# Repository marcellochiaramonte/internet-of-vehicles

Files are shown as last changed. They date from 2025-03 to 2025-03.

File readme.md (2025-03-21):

Internet of Vehicles Project to bring IoT into Electric Vehicles

➡️ [Micropython Pycom Module Code](./2_Software_Module)

➡️ [Fullstack Web App Springboot Angular](./3_Software_Cloud/iov-full-stack-app)

list
battery
map
system
board

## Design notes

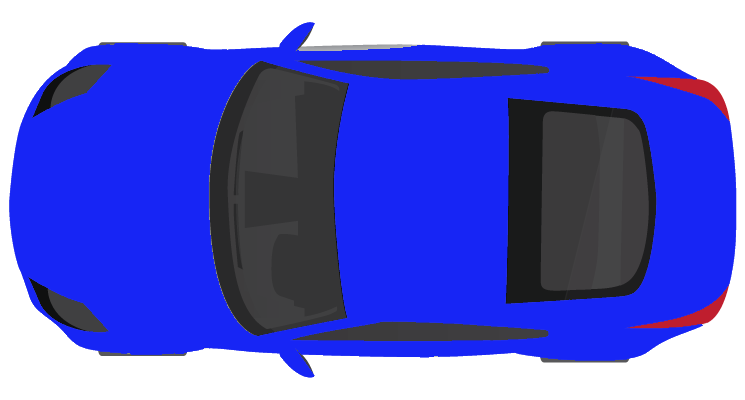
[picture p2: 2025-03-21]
3_Software_Cloud/iov-full-stack-app/frontend-map/iov-frontend/src/assets/img/car-blue.png

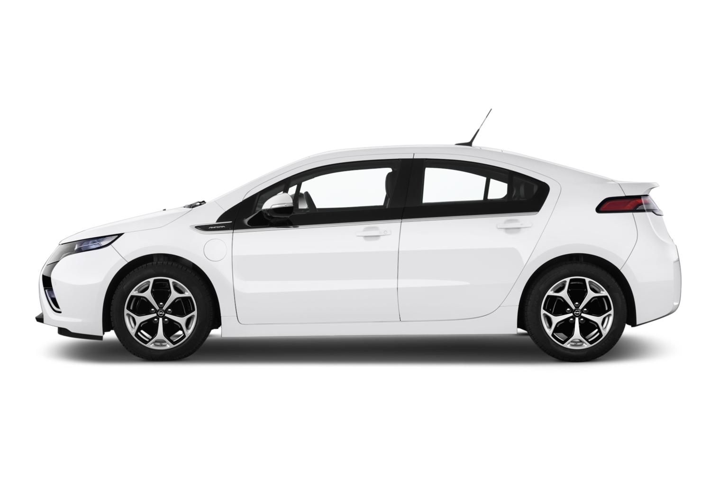
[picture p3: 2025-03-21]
3_Software_Cloud/iov-full-stack-app/frontend-map/iov-frontend/src/assets/img/opel-ampera.png

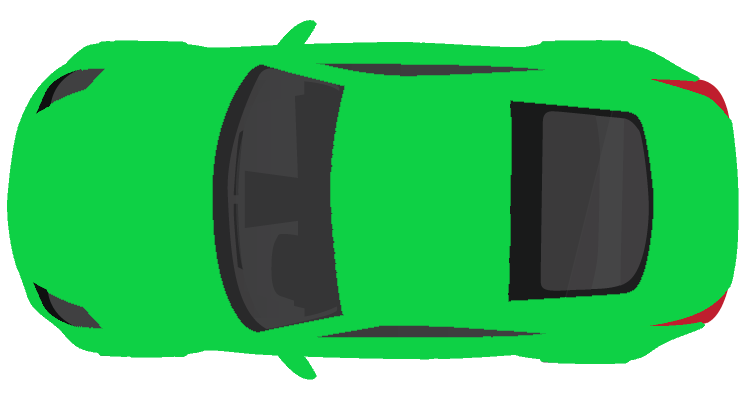
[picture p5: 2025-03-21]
3_Software_Cloud/iov-full-stack-app/frontend-map/iov-frontend/src/assets/img/car-green.png

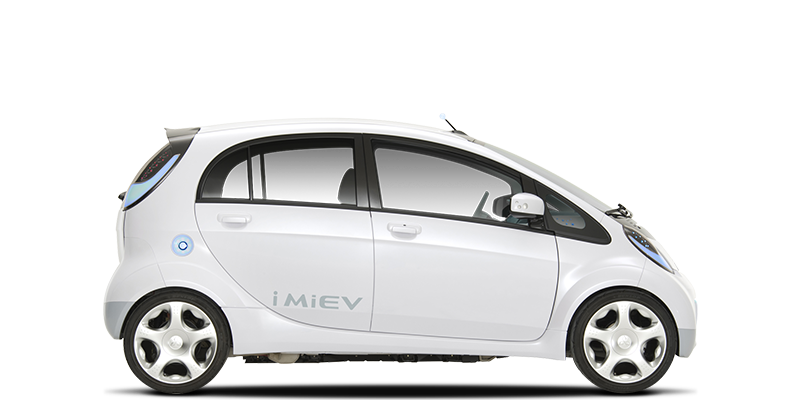
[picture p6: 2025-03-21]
3_Software_Cloud/iov-full-stack-app/frontend-map/iov-frontend/src/assets/img/mitsubishi-i-miev.png

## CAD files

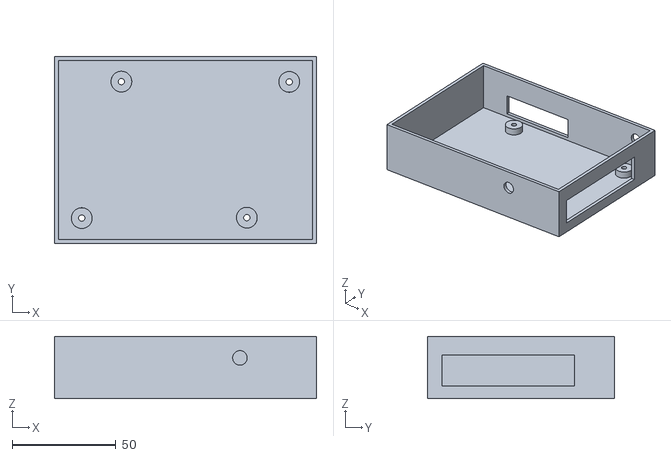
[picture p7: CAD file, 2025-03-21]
4_Case_3D_Printed/stl_models/box/bottom_walls_full_assembly.stl
126.0 x 90.0 x 30.0

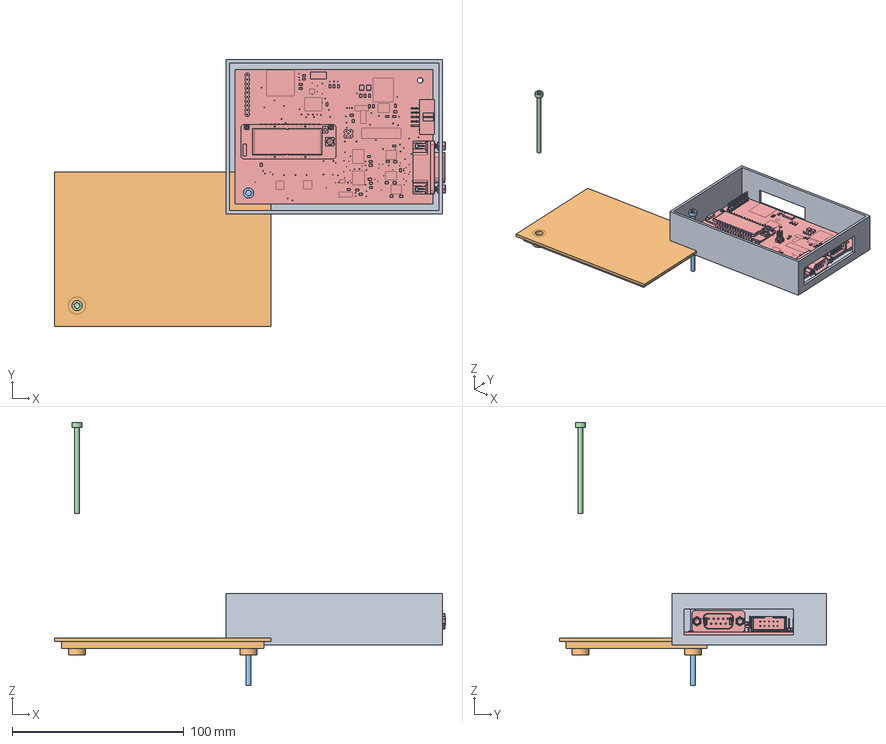
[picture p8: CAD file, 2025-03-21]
4_Case_3D_Printed/freecad_models/AA_full_assembly.FCStd
227.5 x 155.5 x 153.1 mm
bottom_walls_full_assembly_001
cover_mounted_001
m3screw_001
m3screw_002
OVMS v7 v11_001

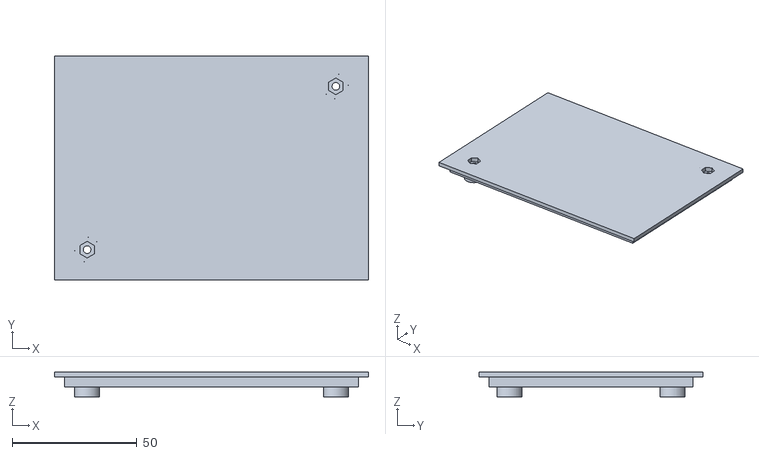
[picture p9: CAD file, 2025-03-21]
4_Case_3D_Printed/stl_models/cover/cover_mounted.stl
126.0 x 90.0 x 10.0

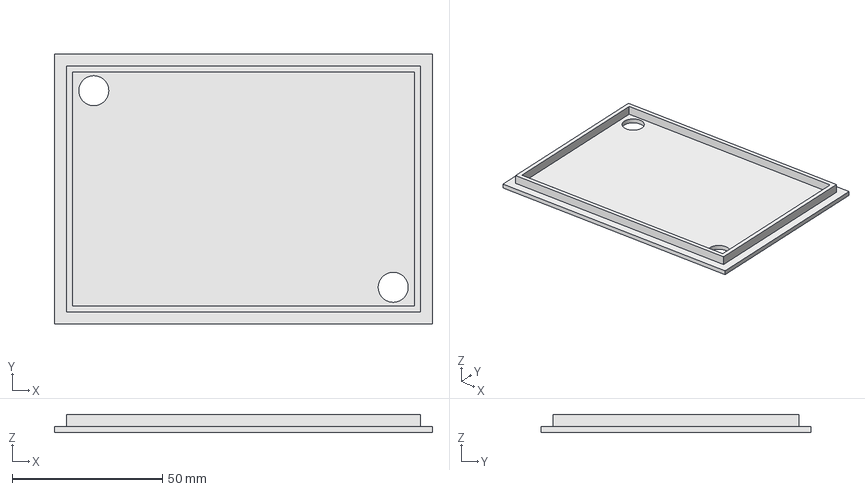
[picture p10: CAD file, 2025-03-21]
4_Case_3D_Printed/freecad_models/cover.FCStd
126.0 x 90.0 x 6.00 mm

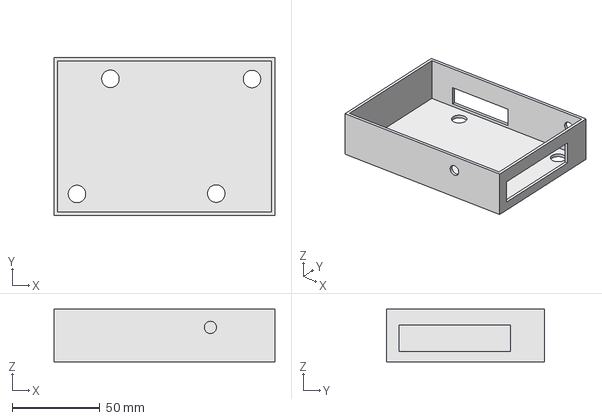
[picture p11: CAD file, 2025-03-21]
4_Case_3D_Printed/freecad_models/bottom_and_walls.FCStd
126.0 x 90.0 x 30.0 mm

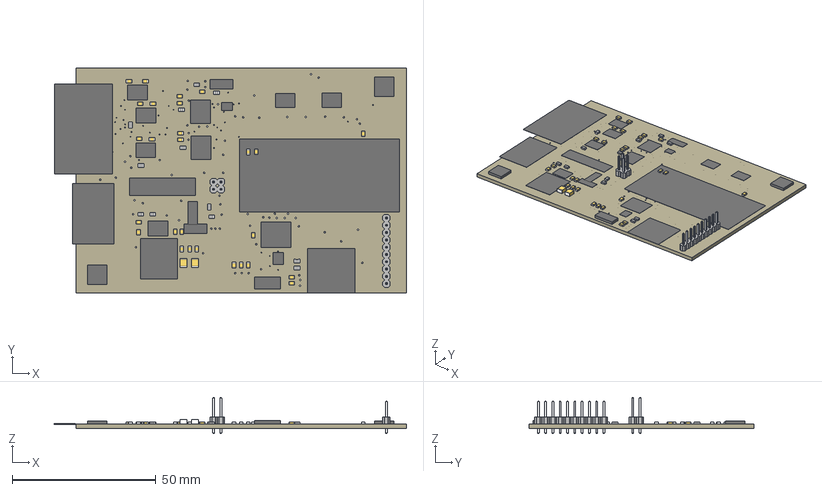
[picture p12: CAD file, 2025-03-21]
4_Case_3D_Printed/freecad_models/iov-board-1.stp
122.6 x 78.3 x 12.6 mm
Board
3_3_UH
SOP65P780X200-28N
DDA0008J
LITTLEFUSE_658
TSSOP20_MC_MCH x 2
OSC_ECS-2520S25-250-FN-TR
D8 x 3
SOT143
USB-B-MICRO-SMD
3,2 x 2
503182-1852_MOL
1X10
2X02
SW_PTS647SM38SMTR2LFS_CNK x 2
PYCOM_GPY-28
C0805 x 27
C1210 x 2
R0805 x 12
SMA_STM x 3
TE_5747840-6

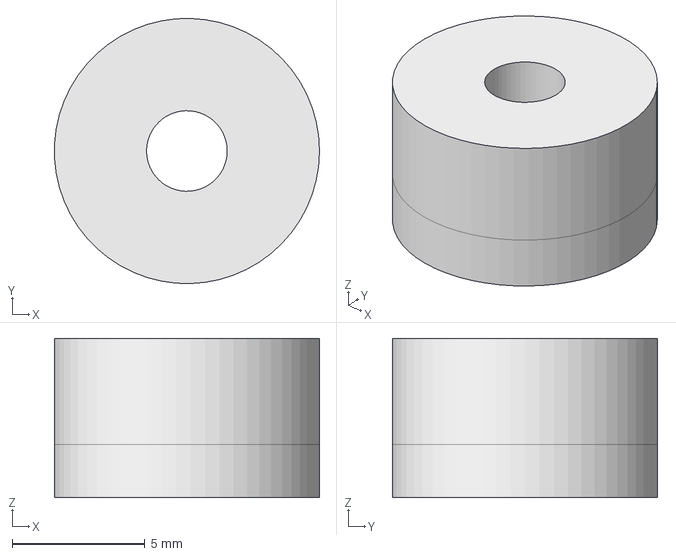
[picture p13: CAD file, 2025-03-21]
4_Case_3D_Printed/freecad_models/screw_holder_bottom.FCStd
9.99 x 10.00 x 6.00 mm

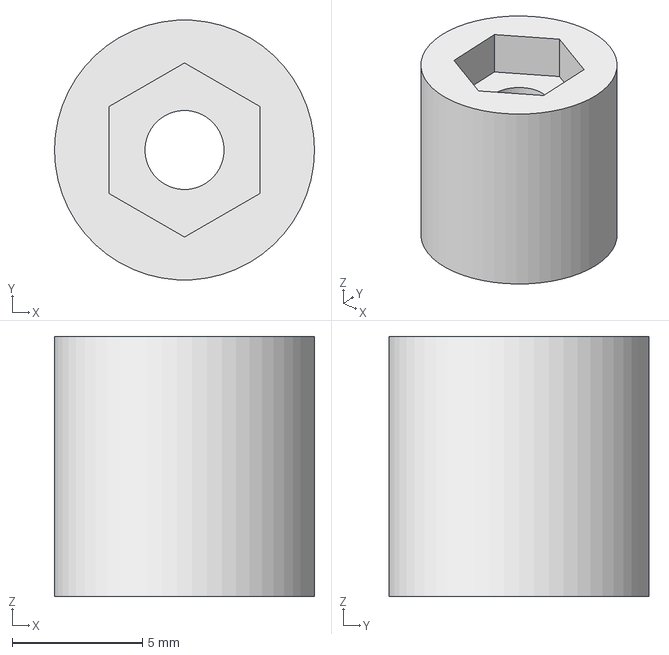
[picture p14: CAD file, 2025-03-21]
4_Case_3D_Printed/freecad_models/screw_holder_top.FCStd
10.0 x 9.98 x 10.0 mm

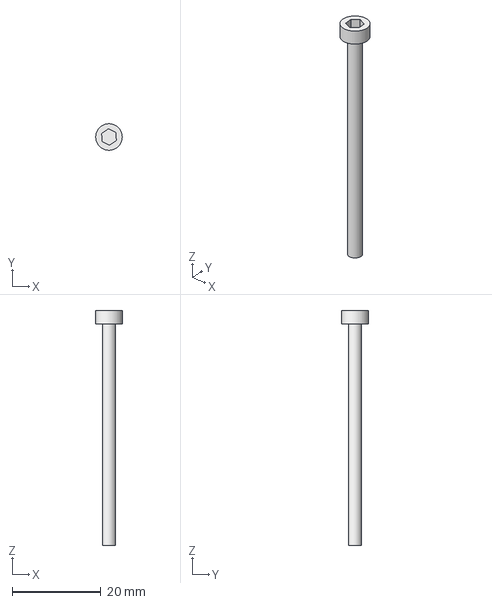
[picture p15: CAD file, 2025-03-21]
4_Case_3D_Printed/freecad_models/m3screw.FCStd
5.99 x 6.00 x 53.0 mm

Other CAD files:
4_Case_3D_Printed/freecad_models/bottom_walls_full_assembly.FCStd
4_Case_3D_Printed/freecad_models/cover_mounted.FCStd

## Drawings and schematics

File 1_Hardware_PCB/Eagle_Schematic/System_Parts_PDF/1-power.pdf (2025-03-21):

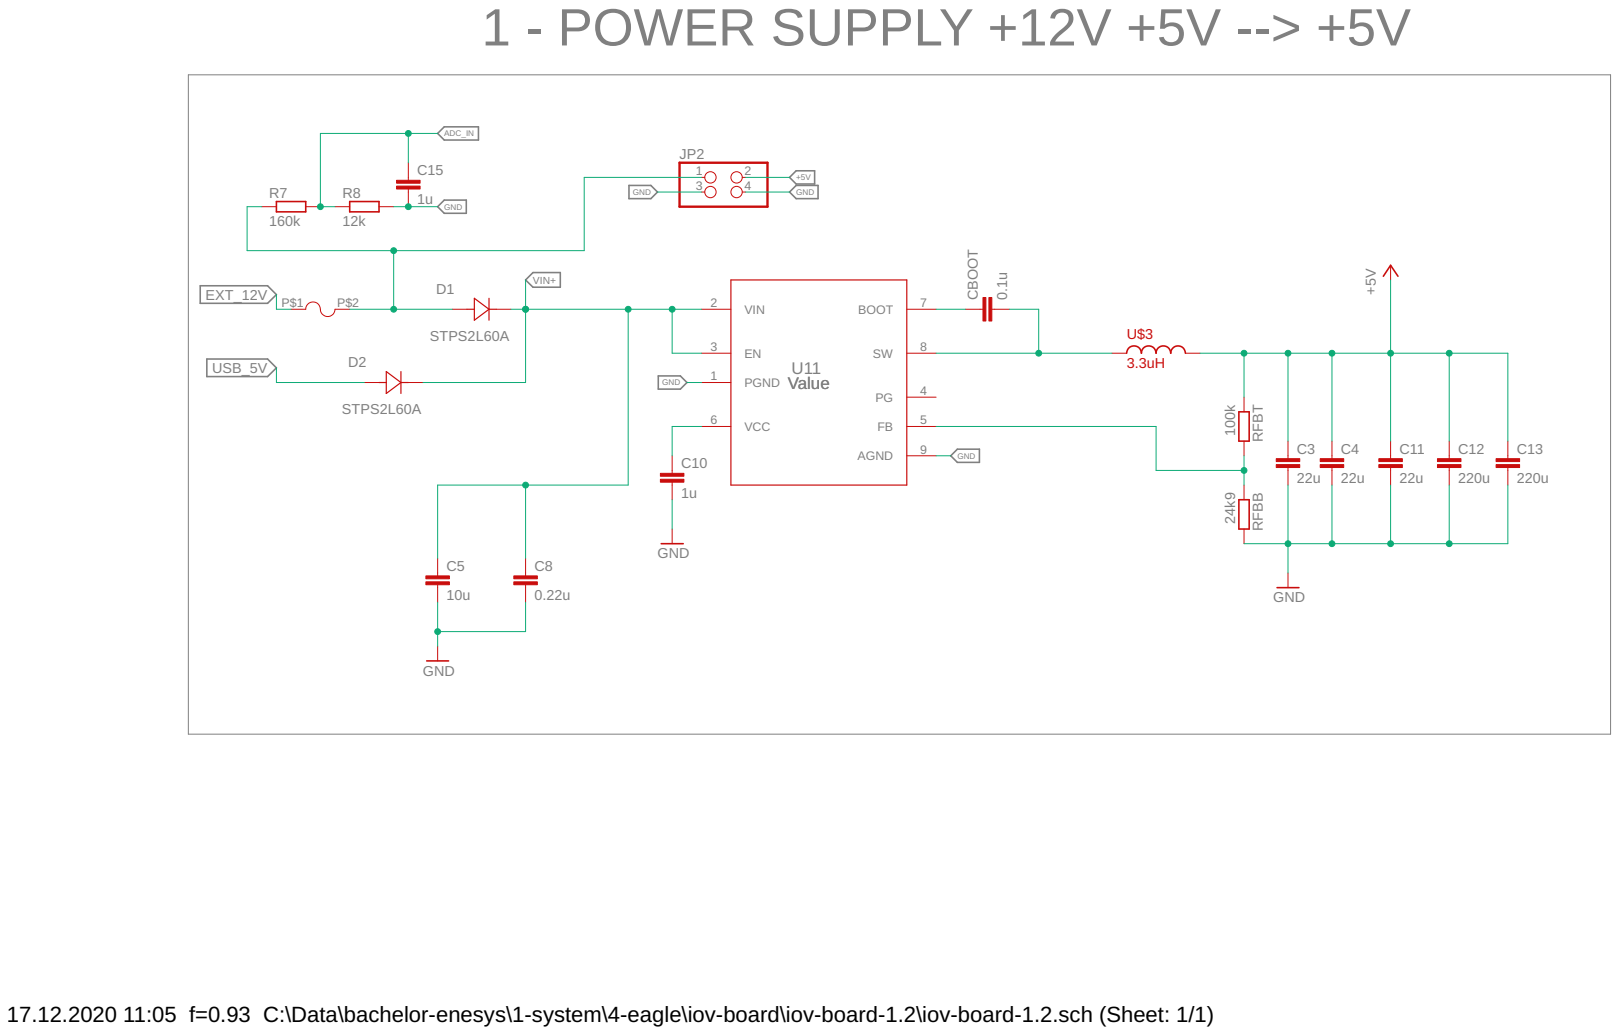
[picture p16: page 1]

17.12.2020 11:05 f=0.93 C:\Data\bachelor-enesys\1-system\4-eagle\iov-board\iov-board-1.2\iov-board-1.2.sch (Sheet: 1/1)

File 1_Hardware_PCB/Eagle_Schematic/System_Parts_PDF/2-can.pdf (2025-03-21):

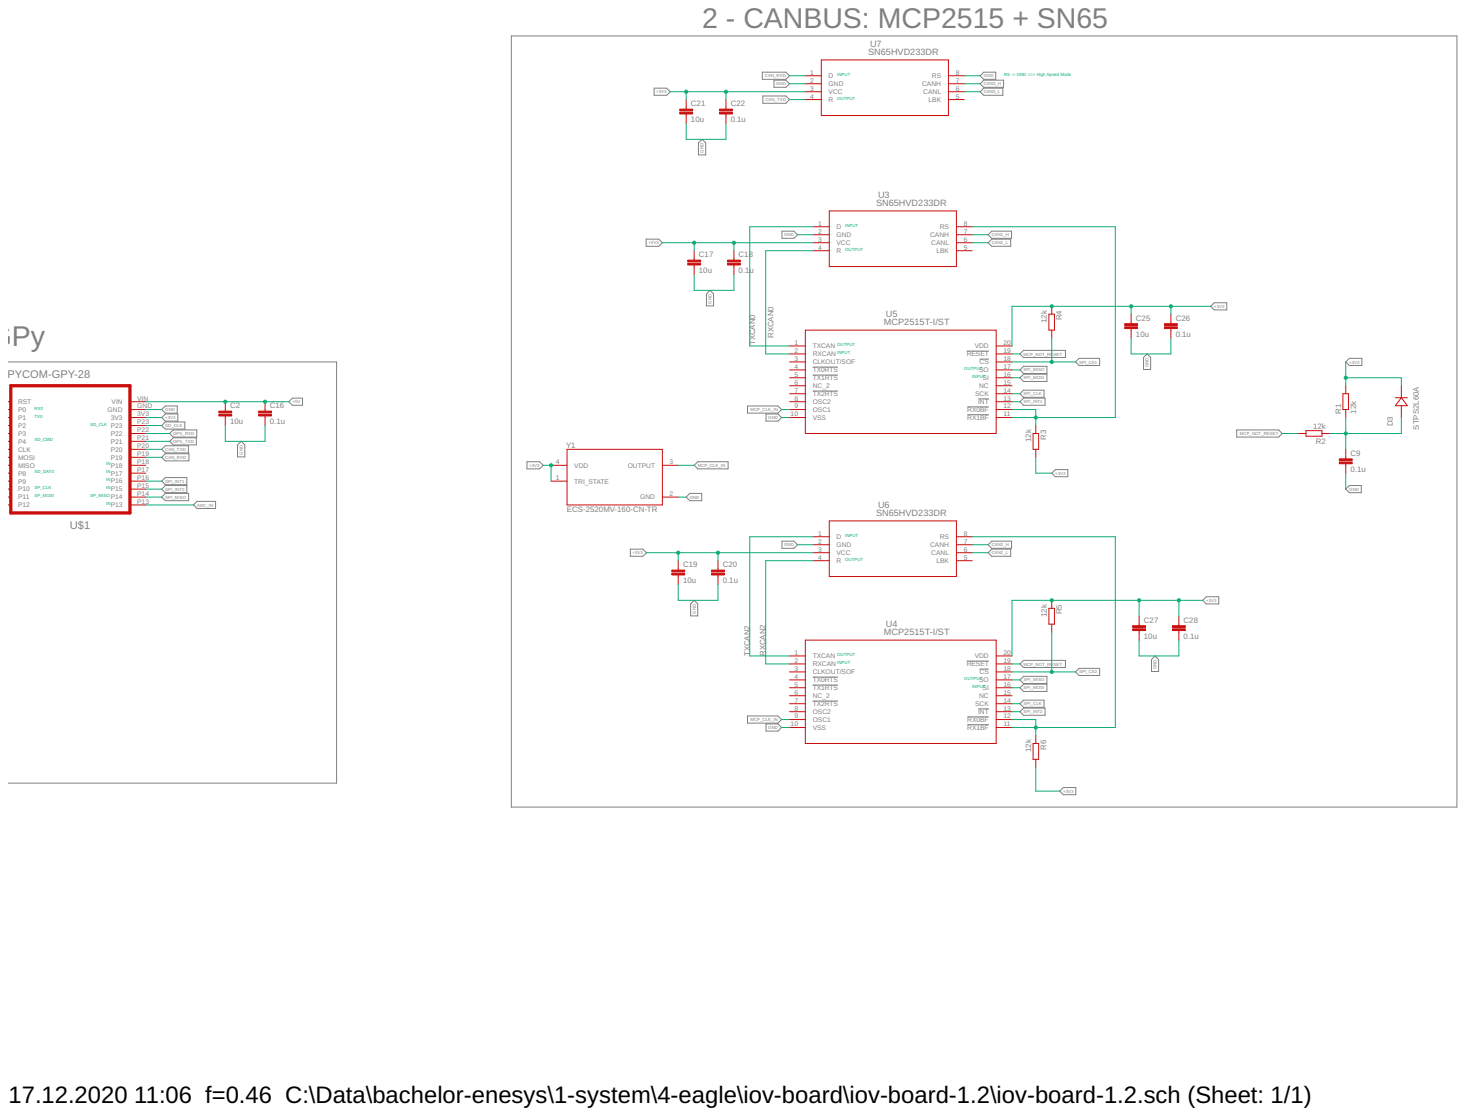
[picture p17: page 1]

RS -> GND ==> High Speed Mode

17.12.2020 11:06 f=0.46 C:\Data\bachelor-enesys\1-system\4-eagle\iov-board\iov-board-1.2\iov-board-1.2.sch (Sheet: 1/1)

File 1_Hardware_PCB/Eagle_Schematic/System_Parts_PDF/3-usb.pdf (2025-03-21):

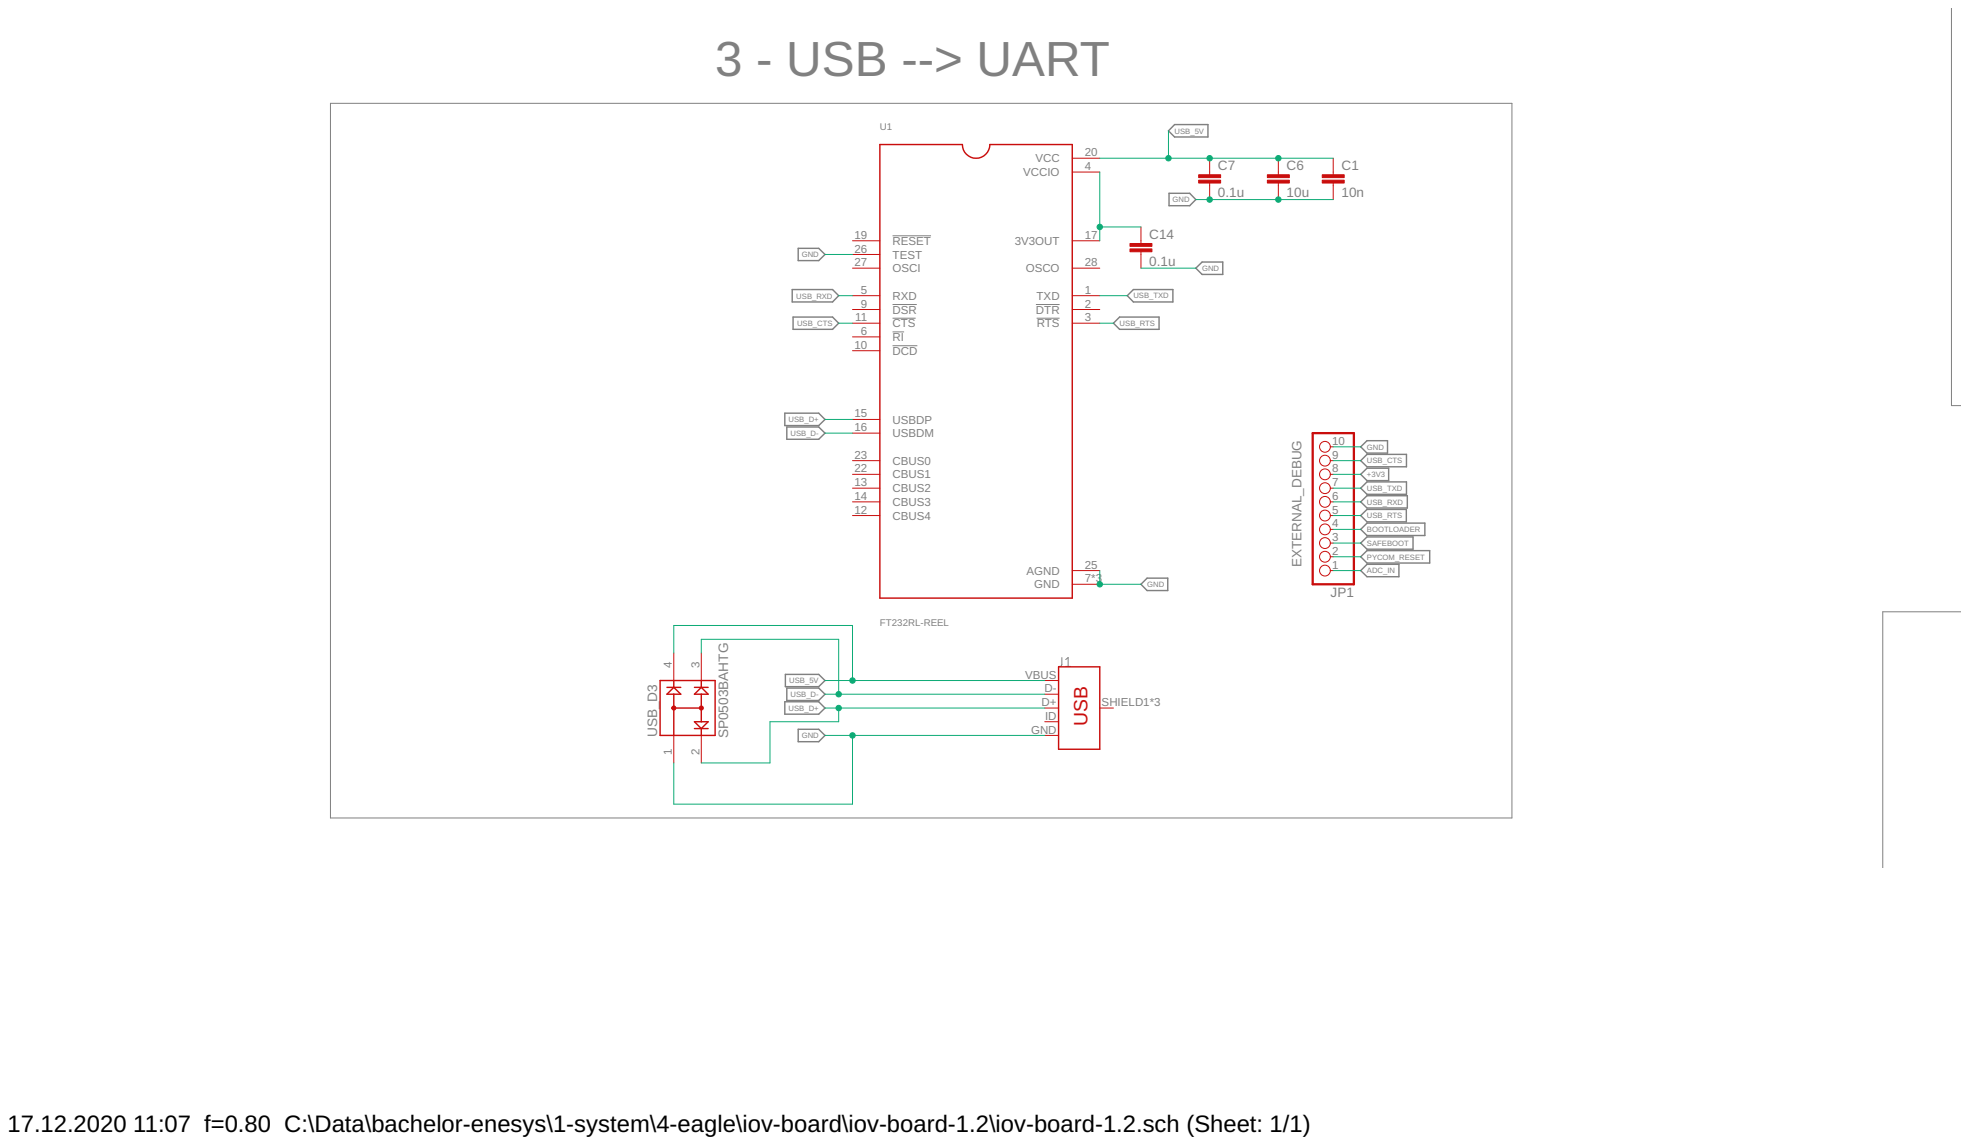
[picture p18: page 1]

17.12.2020 11:07 f=0.80 C:\Data\bachelor-enesys\1-system\4-eagle\iov-board\iov-board-1.2\iov-board-1.2.sch (Sheet: 1/1)

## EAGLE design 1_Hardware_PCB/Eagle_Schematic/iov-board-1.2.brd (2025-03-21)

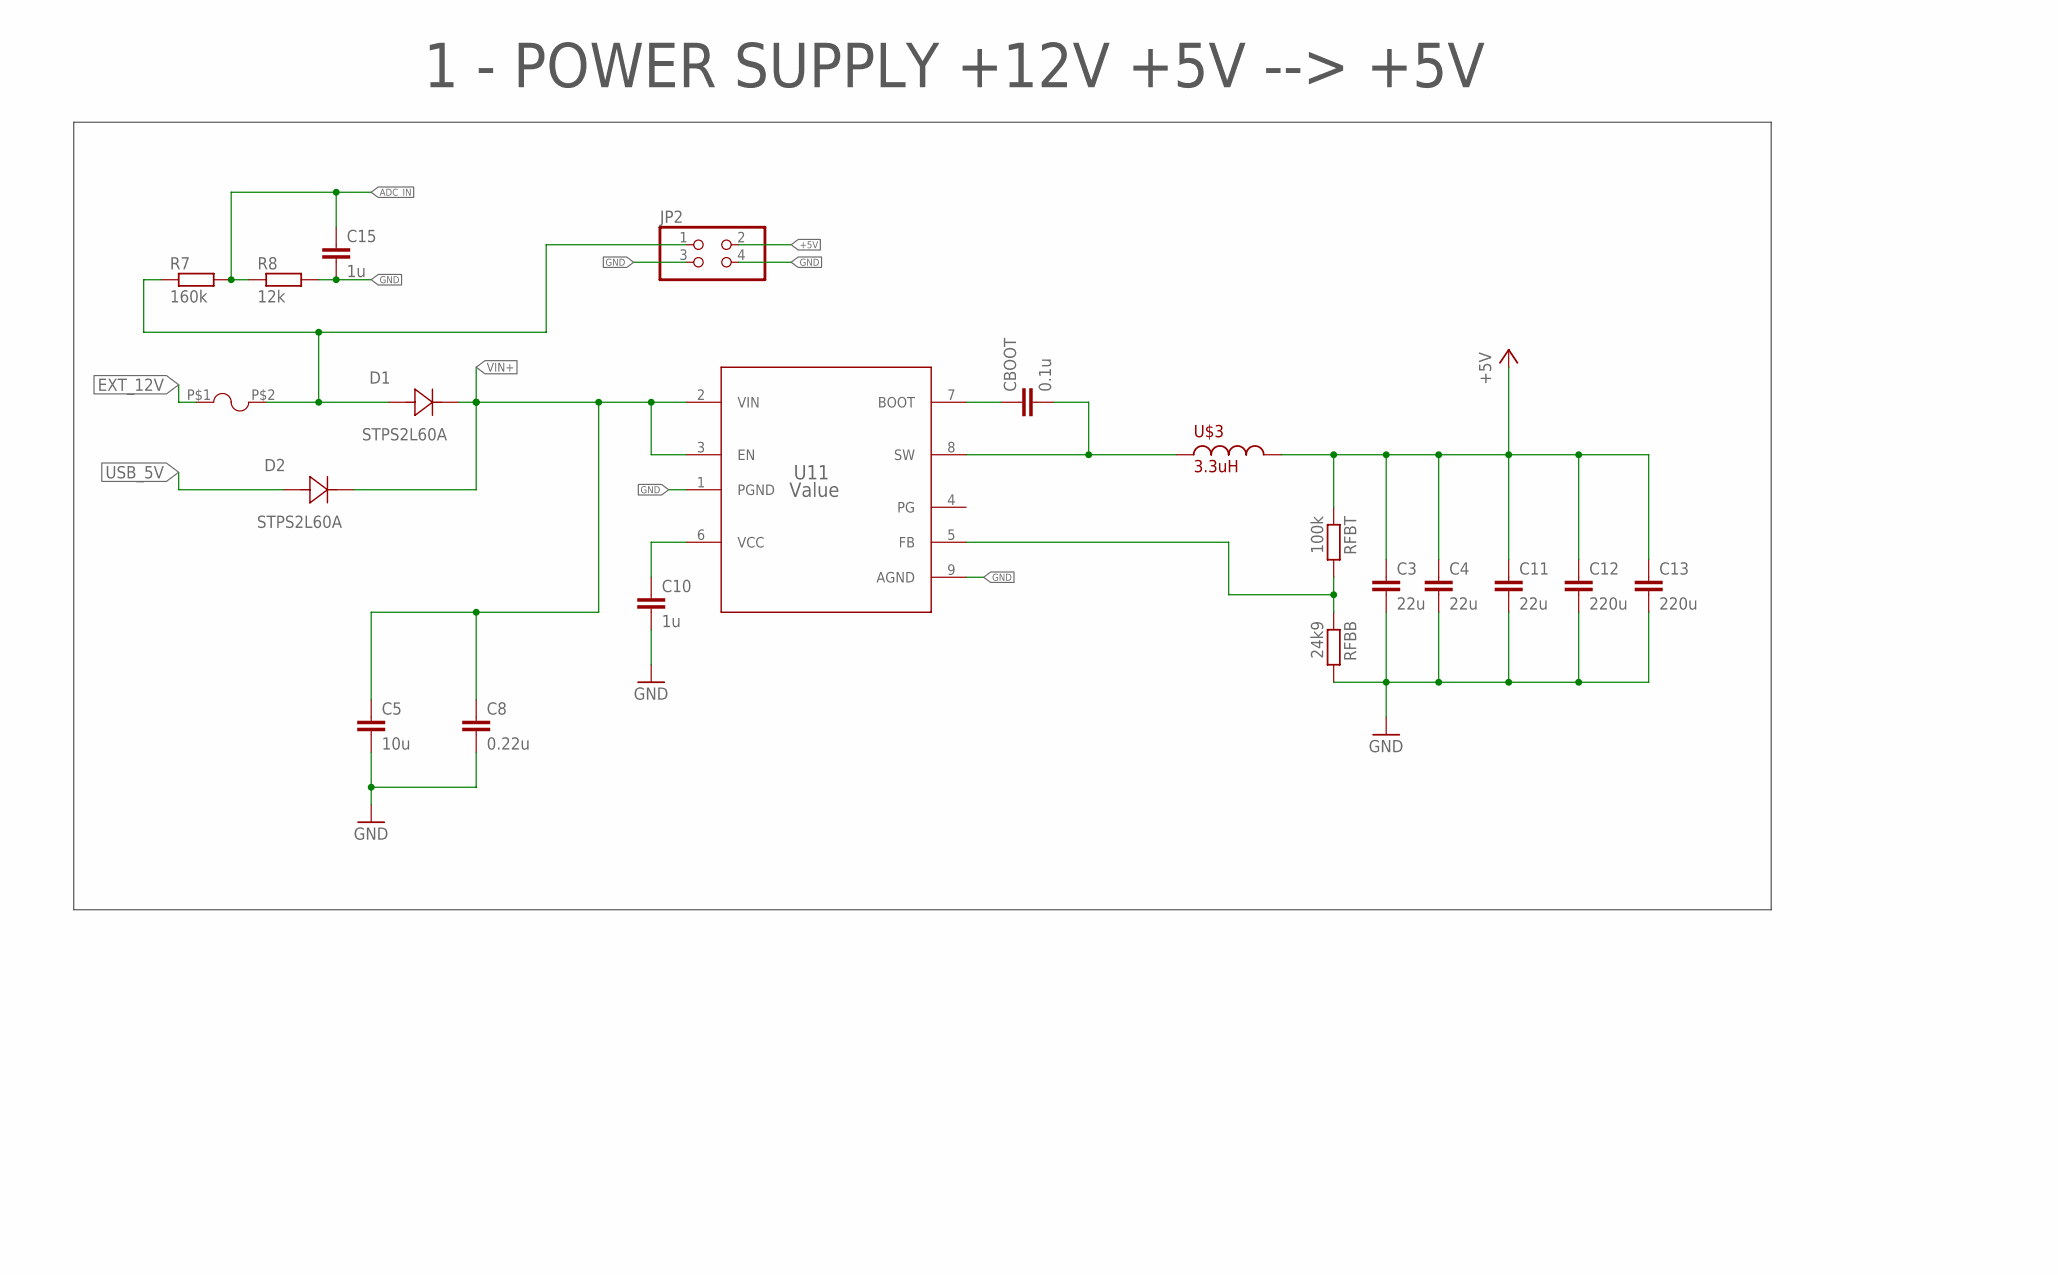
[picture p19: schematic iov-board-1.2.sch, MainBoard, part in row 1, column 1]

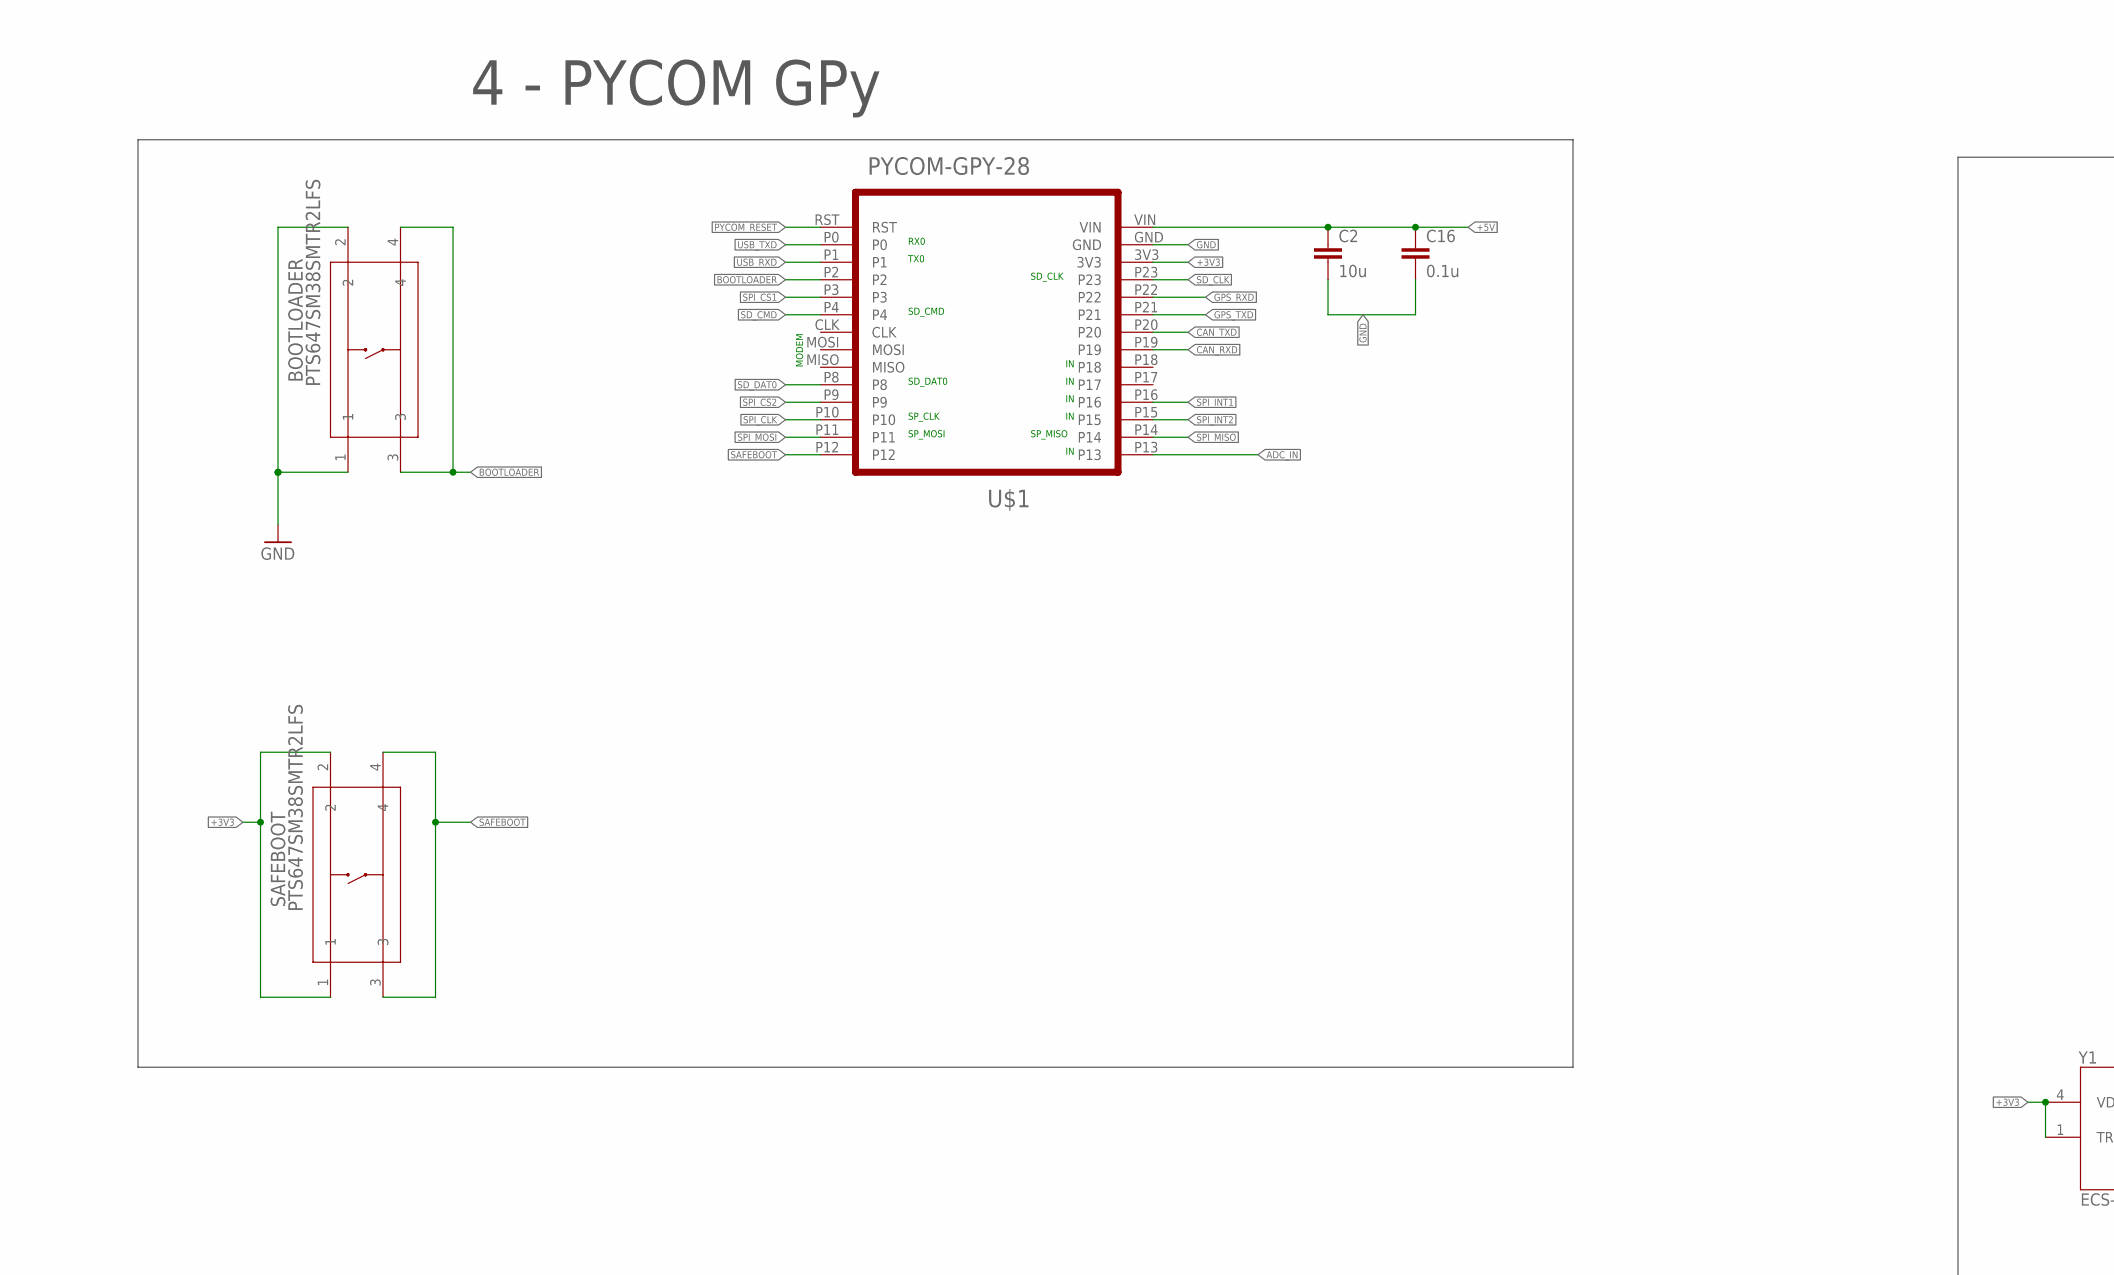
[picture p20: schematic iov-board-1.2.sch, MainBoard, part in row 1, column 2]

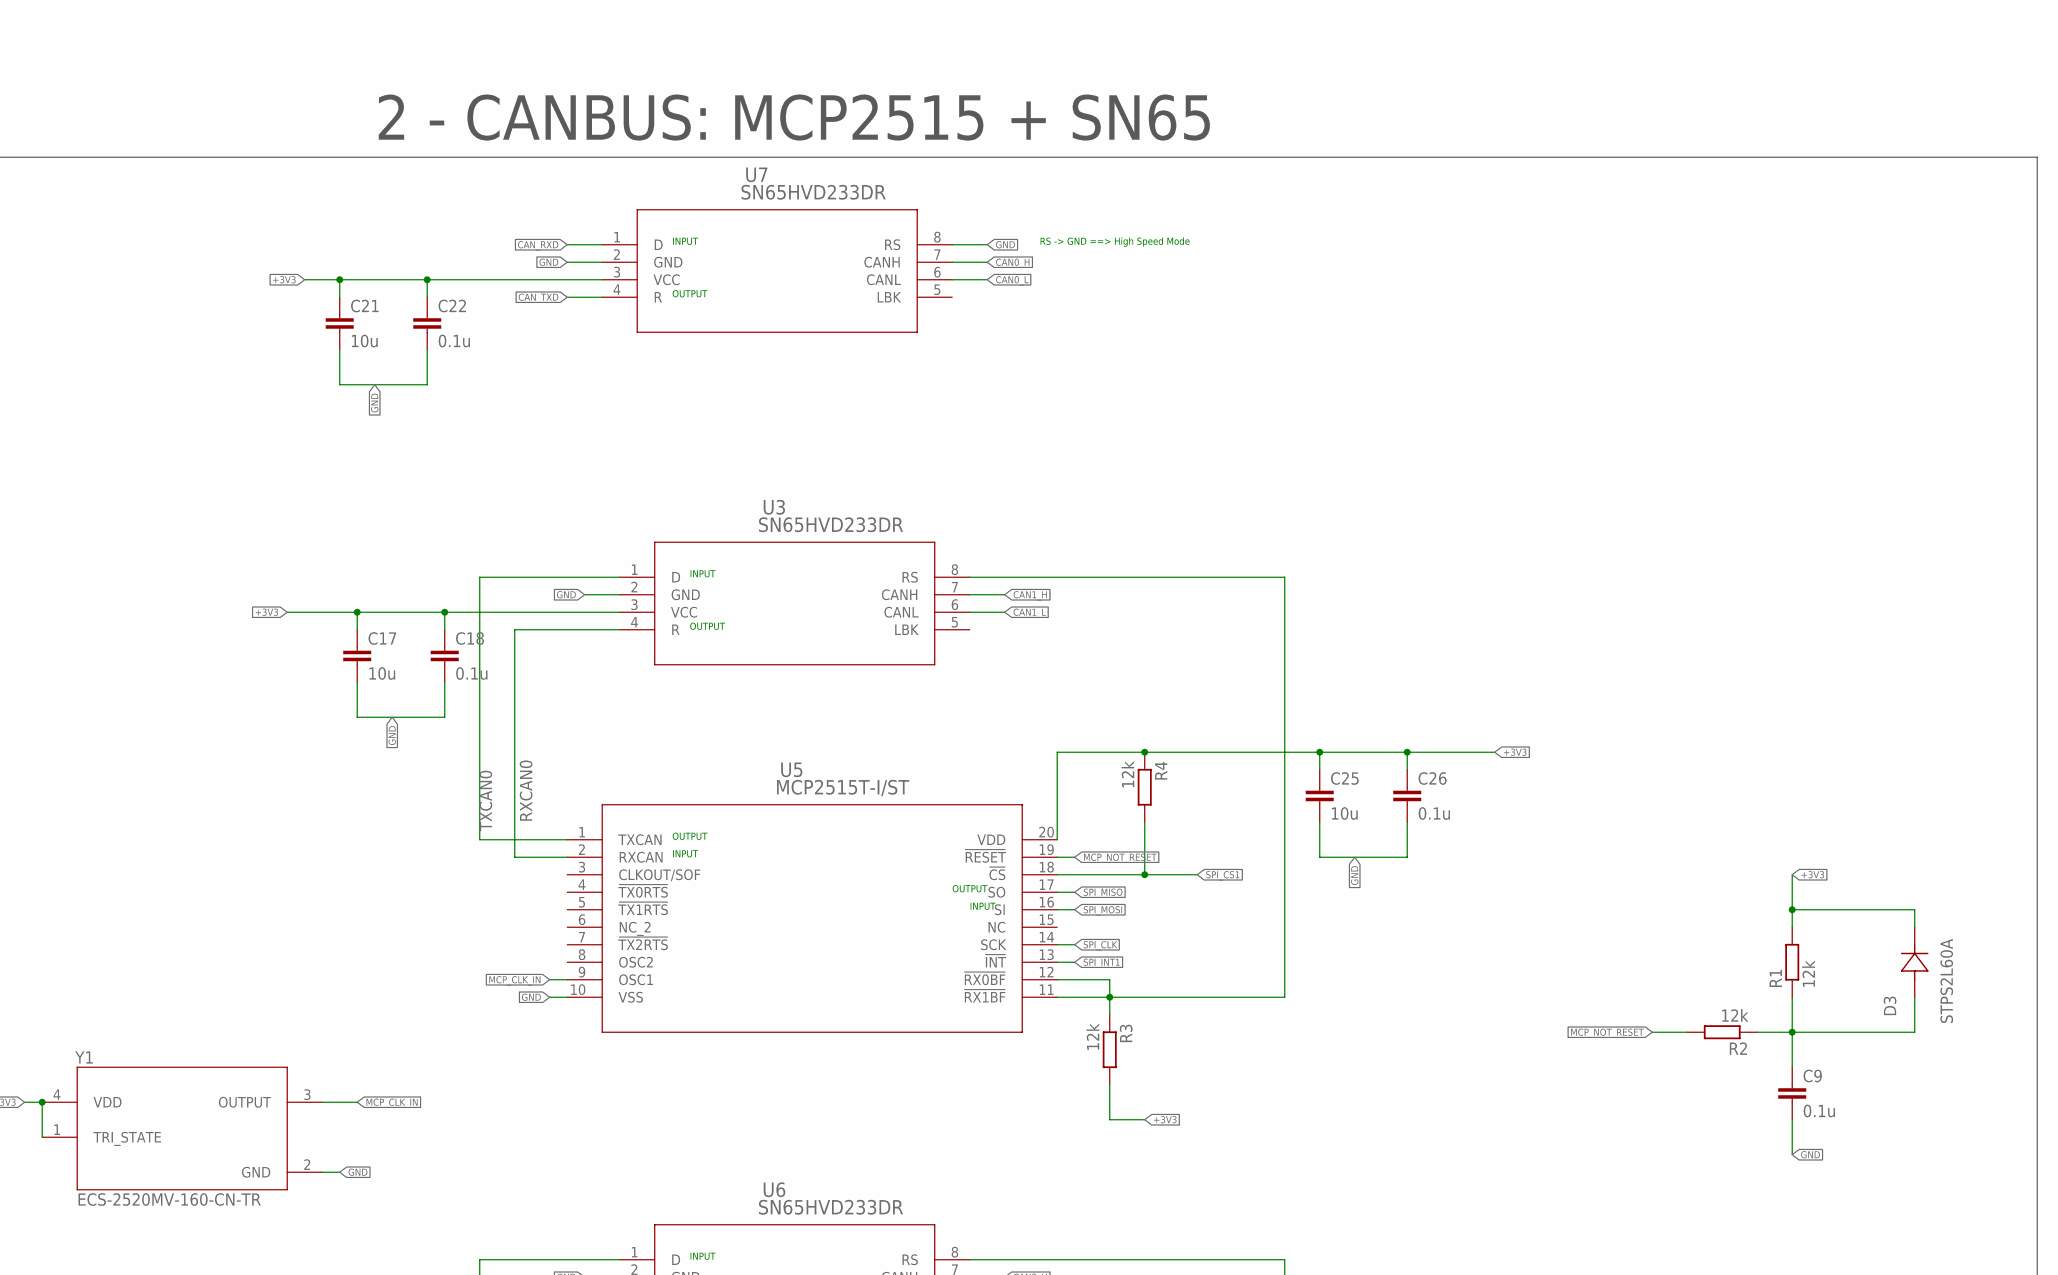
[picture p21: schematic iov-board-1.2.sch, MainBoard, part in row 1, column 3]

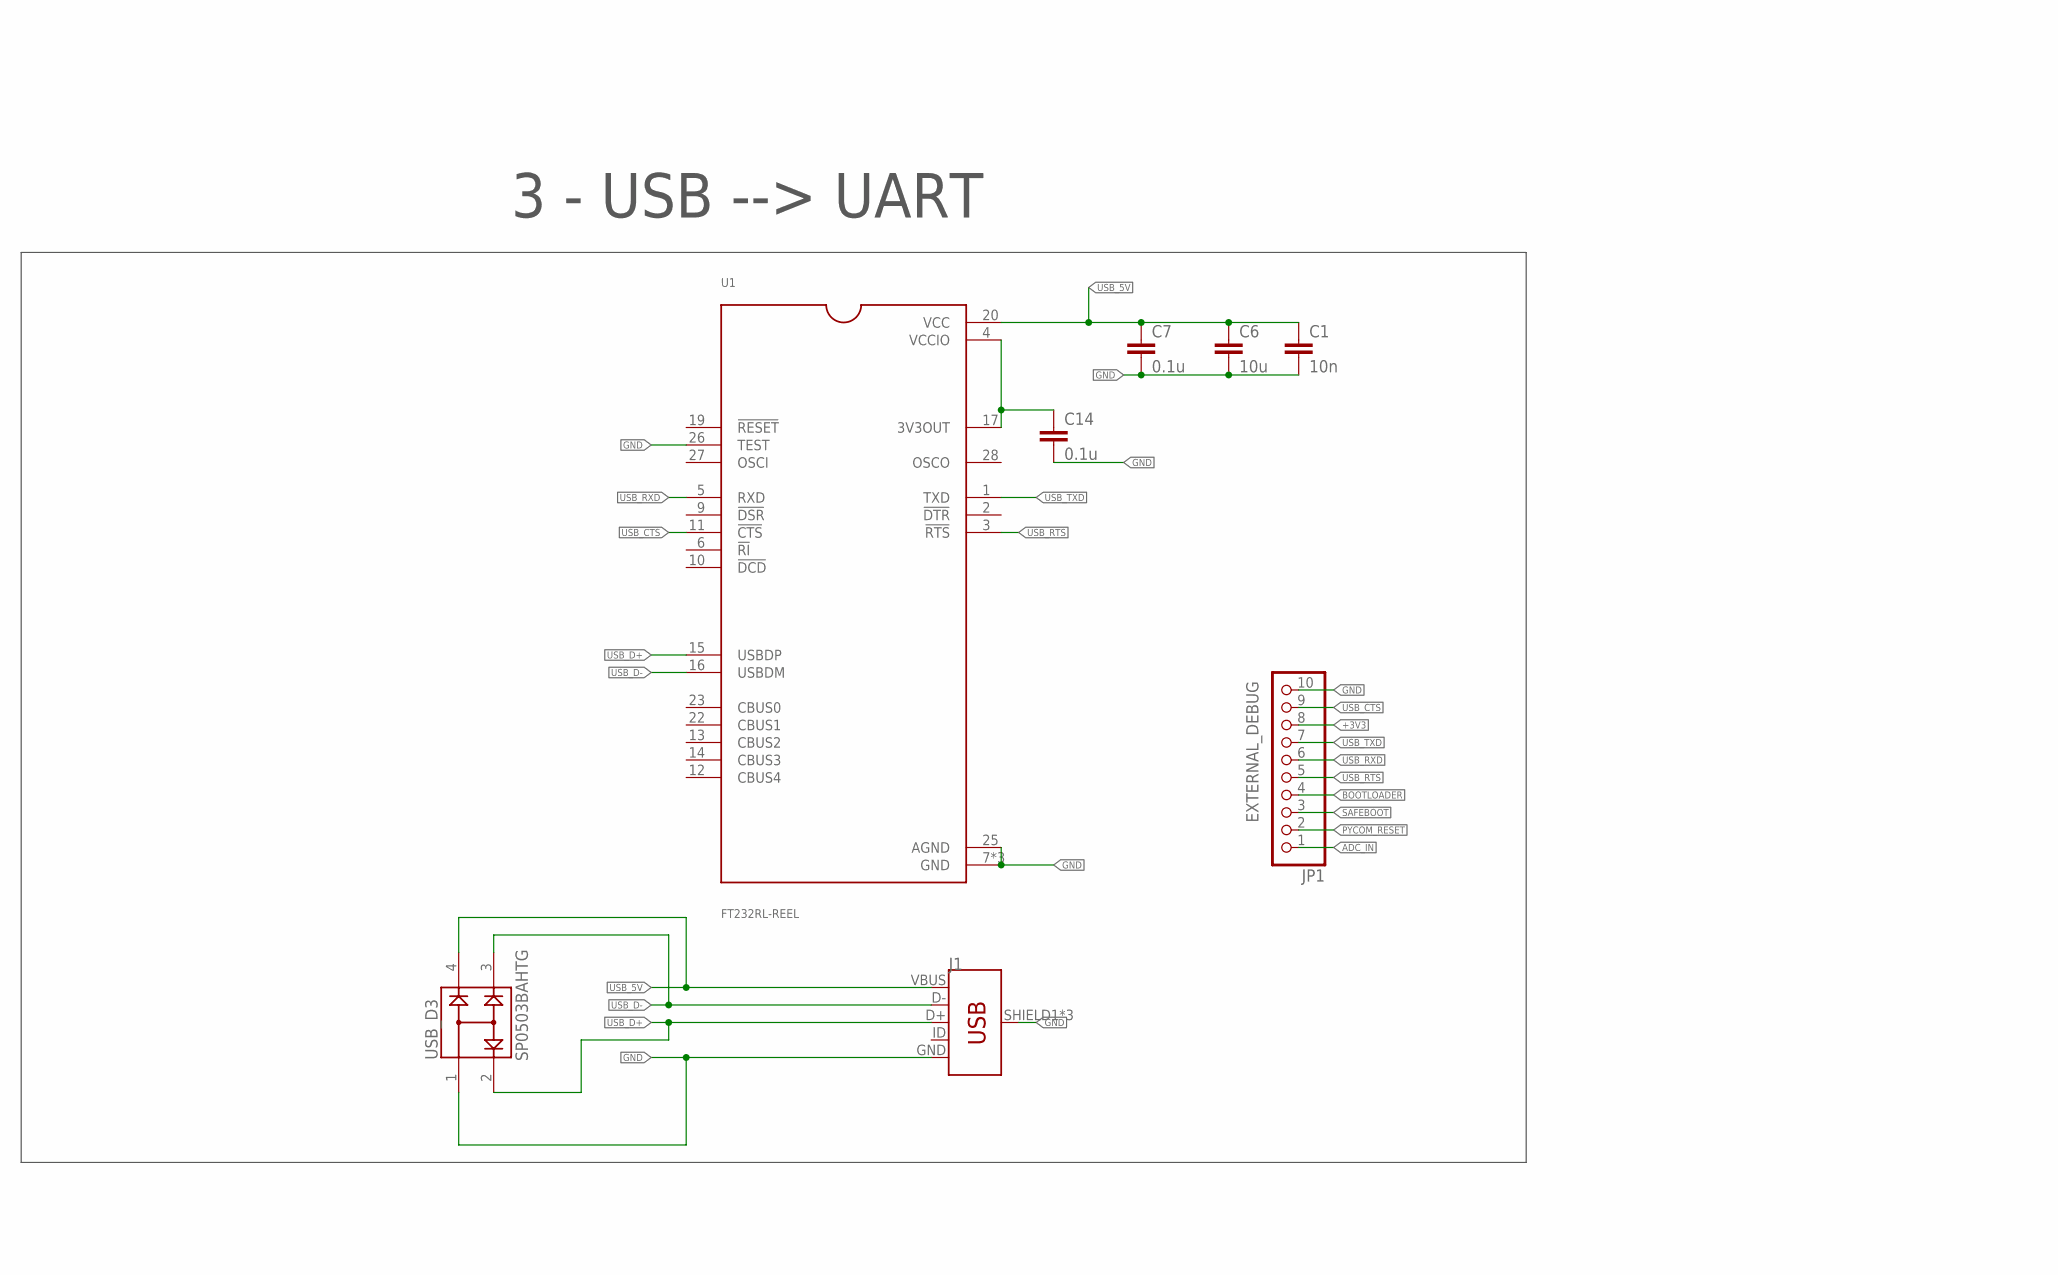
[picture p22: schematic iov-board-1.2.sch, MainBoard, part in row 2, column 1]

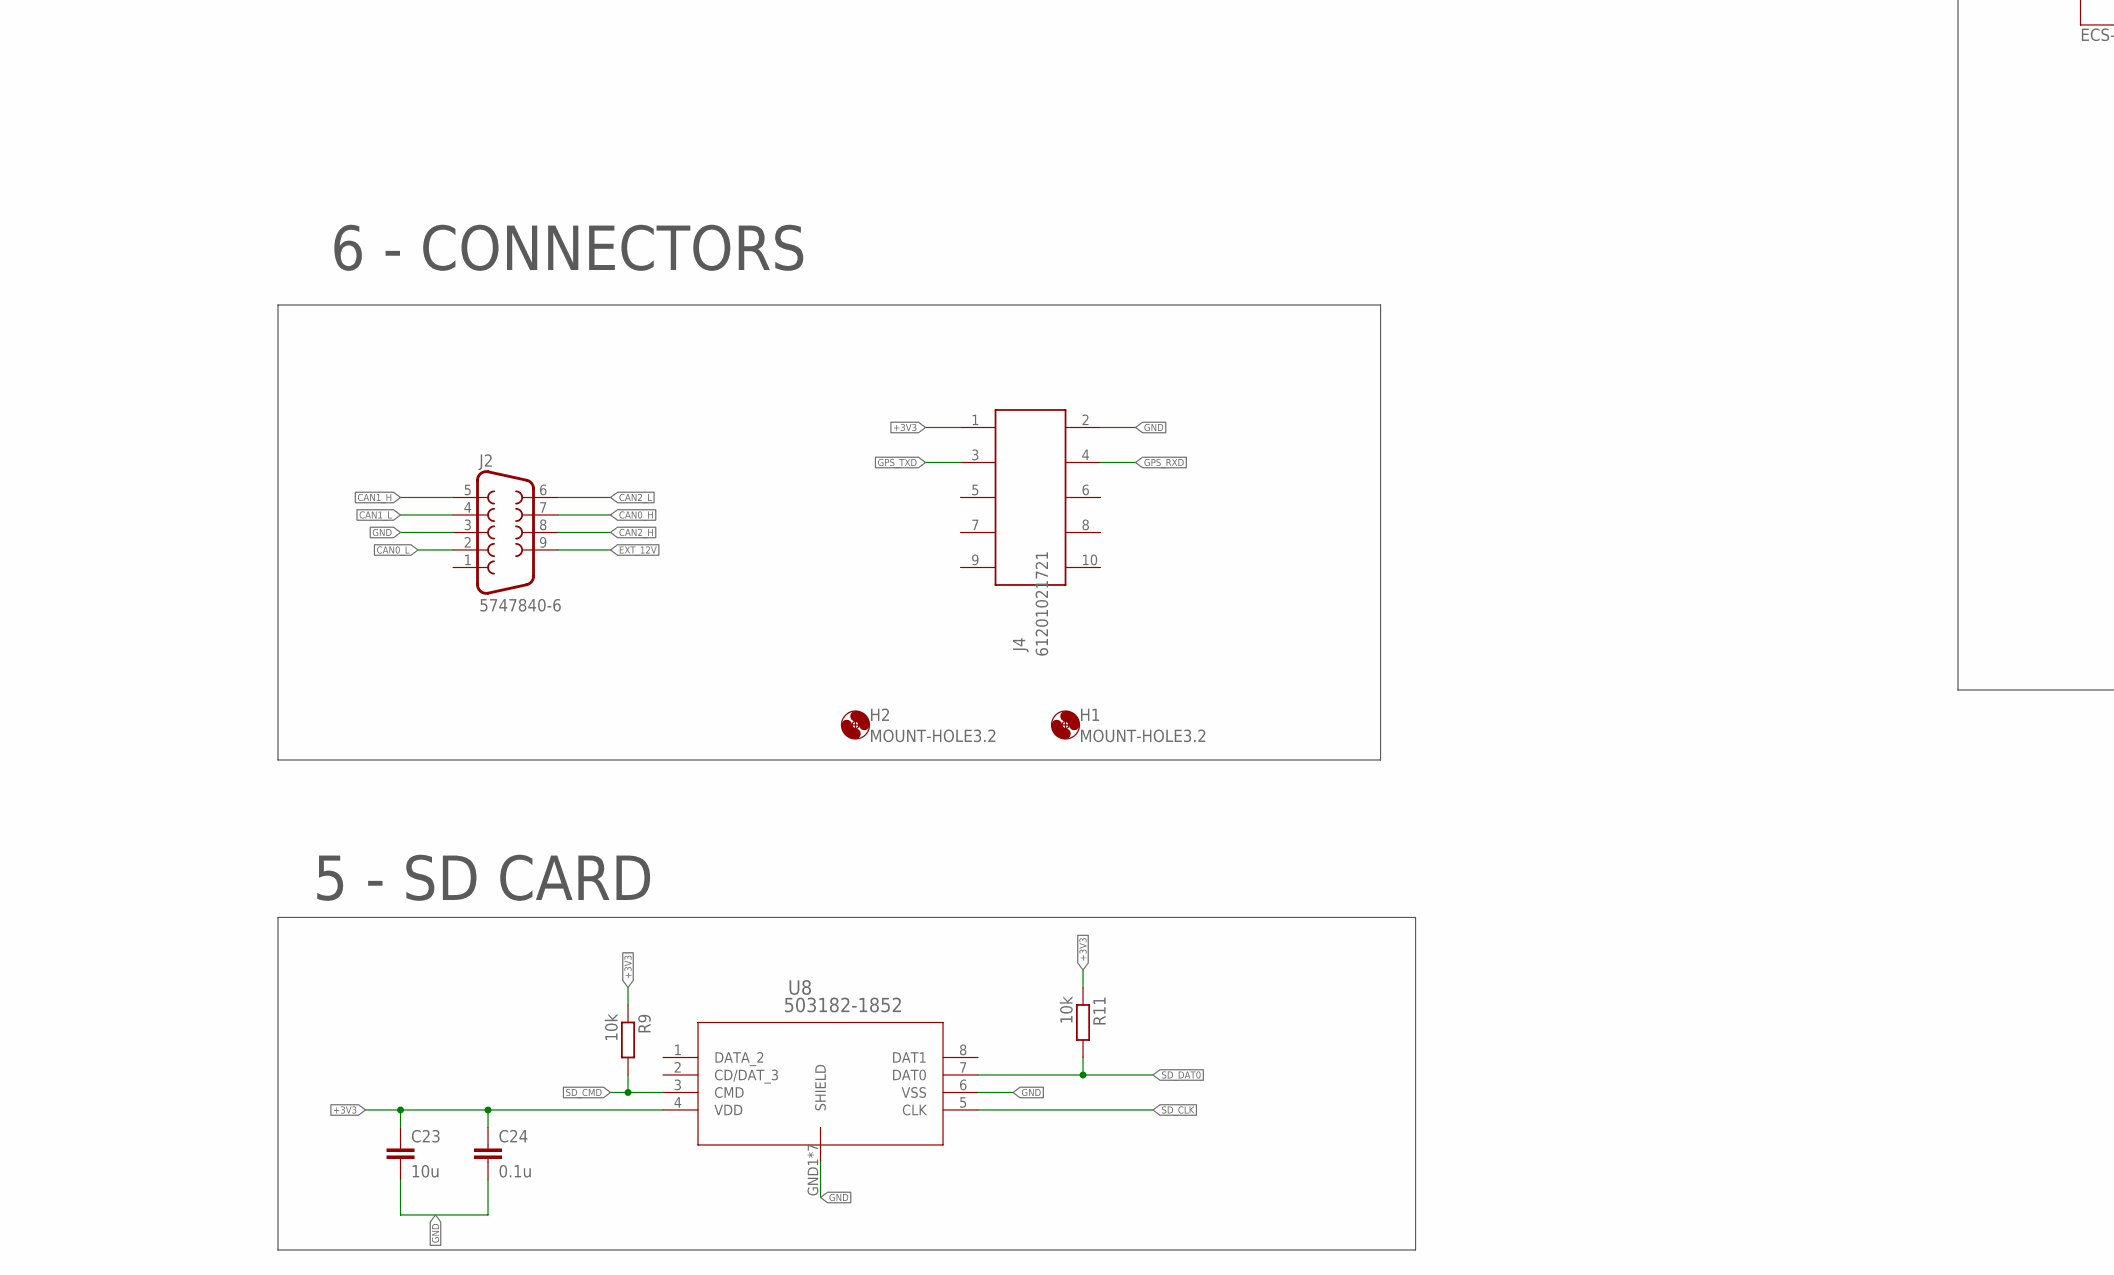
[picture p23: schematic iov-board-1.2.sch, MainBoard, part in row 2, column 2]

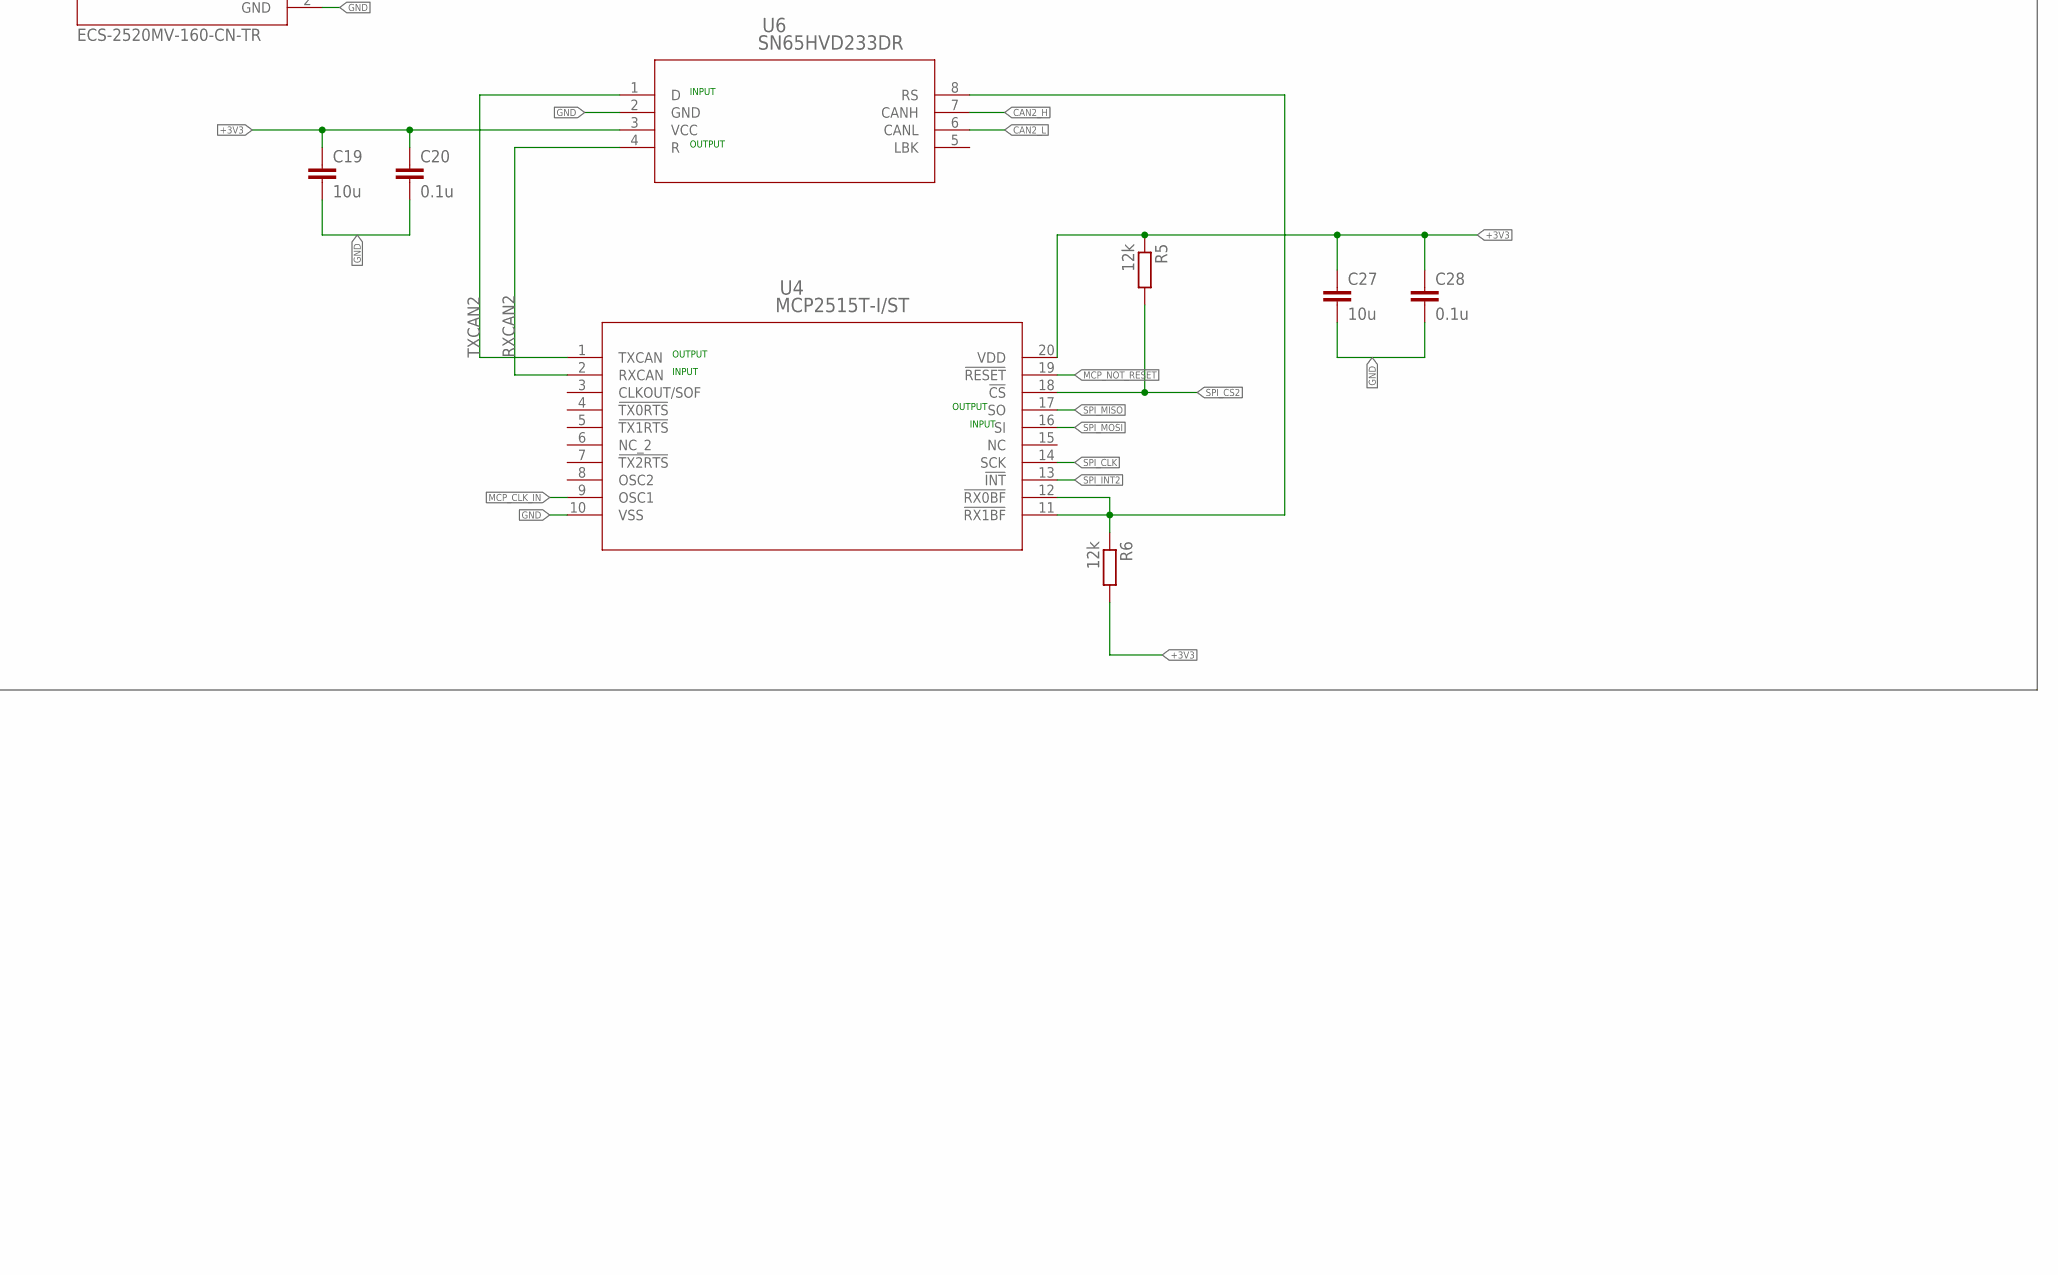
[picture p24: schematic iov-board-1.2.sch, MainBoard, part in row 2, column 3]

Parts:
BOOTLOADER: PTS647SM38SMTR2LFS; SW_PTS647SM38SMTR2LFS_CNK
C1: 10n; C0805
C2, C5, C6, C17, C19, C21, C23, C25, C27: 10u; C0805
C3, C4, C11: 22u; C0805
C7, C9, C14, C16, C18, C20, C22, C24, C26, C28: 0.1u; C0805
C8: 0.22u; C0805
C10, C15: 1u; C0805
C12, C13: 220u; C1210
CBOOT: 0.1u; C0805
D1, D2, D3: STPS2L60A; SMA_STM
H1, H2: MOUNT-HOLE3.2; 3,2
J1: USB_MICRO-B_FEMALE-SMT; USB-B-MICRO-SMD
J2: 5747840-6; TE_5747840-6
J4: 61201021721
JP1: EXTERNAL_DEBUG; 1X10
JP2: PINHD-2X2; 2X02
R1, R2, R3, R4, R5, R6, R8: 12k; R0805
R7: 160k; R0805
R9, R11: 10k; R0805
RFBB: 24k9; R0805
RFBT: 100k; R0805
SAFEBOOT: PTS647SM38SMTR2LFS; SW_PTS647SM38SMTR2LFS_CNK
U1: FT232RL-REEL; SOP65P780X200-28N
U3, U6, U7: SN65HVD233DR; D8
U4, U5: MCP2515T-I/ST; TSSOP20_MC_MCH
U8: 503182-1852; 503182-1852_MOL
U11: Value; DDA0008J
U$1: PYCOM-GPY-28; PYCOM_GPY-28
U$3: 3.3uH; 3_3_UH
U$4: LITTLEFUSE_658
USB_D3: SP0503BAHTG; SOT143
Y1: ECS-2520MV-160-CN-TR; OSC_ECS-2520S25-250-FN-TR

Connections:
+3V3: C17.1, C18.1, C19.1, C20.1, C21.1, C22.1, C23.1, C24.1, C25.1, C26.1, C27.1, C28.1, D3.1, J4.1 (10), JP1.8, R1.2, R3.2, R4.1, R5.1, R6.2, R9.1, R11.1, SAFEBOOT.1, SAFEBOOT.2, U3.3 (VCC), U4.20 (VDD), U5.20 (VDD), U6.3 (VCC), U7.3 (VCC), U8.4 (VDD), U$1.3V3, Y1.1 (TRI_STATE), Y1.4 (VDD)
+5V: C2.1, C3.1, C4.1, C11.1, C12.1, C13.1, C16.1, JP2.2, RFBT.1, U$1.VIN, U$3.P$2
ADC_IN: C15.1, JP1.1, R7.2, R8.1, U$1.P13
BOOTLOADER: BOOTLOADER.3, BOOTLOADER.4, JP1.4, U$1.P2
CAN0_H: J2.7, U7.7 (CANH)
CAN0_L: J2.2, U7.6 (CANL)
CAN1_H: J2.5, U3.7 (CANH)
CAN1_L: J2.4, U3.6 (CANL)
CAN2_H: J2.8, U6.7 (CANH)
CAN2_L: J2.6, U6.6 (CANL)
CAN_RXD: U7.1 (D), U$1.P19
CAN_TXD: U7.4 (R), U$1.P20
EXT_12V: J2.9, U$4.P$1
FB1: RFBB.1, RFBT.2, U11.5 (FB)
GND: BOOTLOADER.1, BOOTLOADER.2, C1.2, C2.2, C3.2, C4.2, C5.2, C6.2, C7.2, C8.2, C9.2, C10.2, C11.2, C12.2, C13.2, C14.2, C15.2, C16.2, C17.2, C18.2, C19.2, C20.2, C21.2, C22.2, C23.2, C24.2, C25.2, C26.2, C27.2, C28.2, J1.GND, J1.SHIELD1 (SHIELD), J1.SHIELD2 (SHIELD), J1.SHIELD3 (SHIELD), J2.3, J4.2 (9), JP1.10, JP2.3, JP2.4, R8.2, RFBB.2, U1.7 (GND), U1.18 (GND), U1.21 (GND), U1.25 (AGND), U1.26 (TEST), U3.2 (GND), U4.10 (VSS), U5.10 (VSS), U6.2 (GND), U7.2 (GND), U7.8 (RS), U8.6 (VSS), U8.GND1 (SHIELD), U8.GND2 (SHIELD), U8.GND3 (SHIELD), U8.GND4 (SHIELD), U8.GND5 (SHIELD), U8.GND6 (SHIELD), U8.GND7 (SHIELD), U11.1 (PGND), U11.9 (AGND), U$1.GND, USB_D3.1, Y1.2 (GND)
GPS_RXD: J4.4 (7), U$1.P22
GPS_TXD: J4.3 (8), U$1.P21
MCP_CLK_IN: U4.9 (OSC1), U5.9 (OSC1), Y1.3 (OUTPUT)
MCP_NOT_RESET: R2.2, U4.19 (!RESET), U5.19 (!RESET)
unnamed: C10.1, U11.6 (VCC)
unnamed: C14.1, U1.4 (VCCIO), U1.17 (3V3OUT)
unnamed: C9.1, D3.2, R1.1, R2.1
unnamed: D1.2, JP2.1, R7.1, U$4.P$2
unnamed: CBOOT.2, U11.8 (SW), U$3.P$1
unnamed: CBOOT.1, U11.7 (BOOT)
unnamed: R6.1, U4.11 (!RX1BF), U4.12 (!RX0BF), U6.8 (RS)
unnamed: R3.1, U3.8 (RS), U5.11 (!RX1BF), U5.12 (!RX0BF)
PYCOM_RESET: JP1.2, U$1.RST
RXCAN0: U3.4 (R), U5.2 (RXCAN)
RXCAN2: U4.2 (RXCAN), U6.4 (R)
SAFEBOOT: JP1.3, SAFEBOOT.3, SAFEBOOT.4, U$1.P12
SD_CLK: U8.5 (CLK), U$1.P23
SD_CMD: R9.2, U8.3 (CMD), U$1.P4
SD_DAT0: R11.2, U8.7 (DAT0), U$1.P8
SPI_CLK: U4.14 (SCK), U5.14 (SCK), U$1.P10
SPI_CS1: R4.2, U5.18 (!CS), U$1.P3
SPI_CS2: R5.2, U4.18 (!CS), U$1.P9
SPI_INT1: U5.13 (!INT), U$1.P16
SPI_INT2: U4.13 (!INT), U$1.P15
SPI_MISO: U4.17 (SO), U5.17 (SO), U$1.P14
SPI_MOSI: U4.16 (SI), U5.16 (SI), U$1.P11
TXCAN0: U3.1 (D), U5.1 (TXCAN)
TXCAN2: U4.1 (TXCAN), U6.1 (D)
USB_5V: C1.1, C6.1, C7.1, D2.2, J1.VBUS, U1.20 (VCC), USB_D3.4
USB_CTS: JP1.9, U1.11 (!CTS)
USB_D+: J1.D+, U1.15 (USBDP), USB_D3.2
USB_D-: J1.D-, U1.16 (USBDM), USB_D3.3
USB_RTS: JP1.5, U1.3 (!RTS)
USB_RXD: JP1.6, U1.5 (RXD), U$1.P1
USB_TXD: JP1.7, U1.1 (TXD), U$1.P0
VIN+: C5.1, C8.1, D1.1, D2.1, U11.2 (VIN), U11.3 (EN)

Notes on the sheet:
2 - CANBUS: MCP2515 + SN65
6 - CONNECTORS
4 - PYCOM GPy
5 - SD CARD
1 - POWER SUPPLY +12V +5V --> +5V
3 - USB --> UART
SD_CMD
RX0
TX0
SD_DAT0
SD_CLK
SP_MISO
MODEM
SP_CLK
SP_MOSI
INPUT
OUTPUT
RS -> GND ==> High Speed Mode

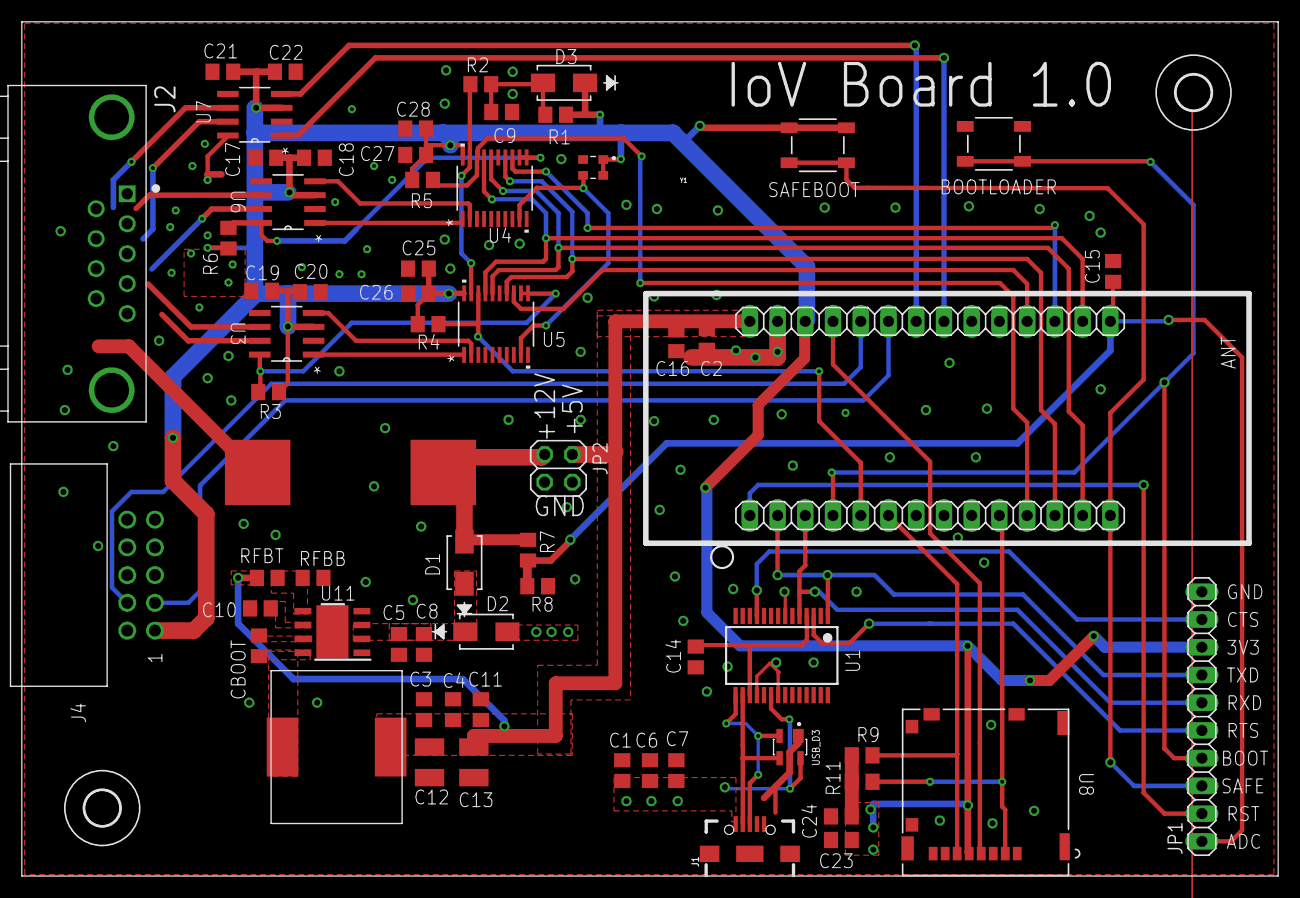
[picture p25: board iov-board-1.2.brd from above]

Board: 2 copper layers, 115.1 x 78.2 mm, 66 parts (0 on the bottom side), 51 nets.

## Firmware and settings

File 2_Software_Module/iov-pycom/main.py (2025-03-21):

import libraries.uasyncio as asyncio
from project.vehicles.base_vehicle import BaseVehicle
from project.can.can_controller import CanController
from machine import reset
import gc

gc.collect()  # garbage collector empty unnecessary cached data in the Stack/RAM


def main():
    print("main func")  # starts the base vehicle class, which calls other dependencies
    vehicle = BaseVehicle()
    gc.collect()
    loop = asyncio.get_event_loop()
    loop.run_forever()


try:
    main()  # main func

except:
    print("exception occoured, reseting module")
finally:
    print("end, resetting")
    reset()

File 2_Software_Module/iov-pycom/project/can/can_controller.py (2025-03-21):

from machine import CAN
import libraries.uasyncio as uasyncio
from project.vehicles.metrics import can_filter_frames

import gc

gc.collect()


class CanController:
    def __init__(self):
        self.can = None
        self.reset_can()
        print("initialized can with soft filtering")

    def reset_can(self):
        self.can = CAN(
            mode=CAN.NORMAL,
            baudrate=500000,
            pins=("P19", "P20"),
            rx_queue_len=512,  # messages on the queue
            frame_format=CAN.FORMAT_STD,  # 11 bit identifier
        )
        self.can.soft_filter(CAN.FILTER_LIST, can_filter_frames)

    def stop_can(self):
        self.can.deinit()

    def set_callback(self, callback_function):  # should be working
        def can_cb(can_obj):  # defines the callback function for a received frame
            try:
                receive_object = can_obj.recv()  # tuple in form (id,data)
                if receive_object:
                    callback_function(receive_object)  # calls the translate_frames function of the vehicle classes
            except:
                print("exception on reading can frame")

        try:
            # disables running threads that might still be active
            self.disable_callback()
            self.can.callback(handler=can_cb, trigger=CAN.RX_FRAME)
        except TypeError as e:
            print("typeerror on callback setup", e)
        print("callback is set")

    def disable_callback(self):
        self.can.callback(handler=None, trigger=CAN.RX_FRAME)
        print("can callback disabled")

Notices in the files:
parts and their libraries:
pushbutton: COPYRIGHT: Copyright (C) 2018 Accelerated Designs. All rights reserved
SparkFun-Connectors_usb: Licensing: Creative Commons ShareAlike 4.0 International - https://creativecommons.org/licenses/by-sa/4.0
